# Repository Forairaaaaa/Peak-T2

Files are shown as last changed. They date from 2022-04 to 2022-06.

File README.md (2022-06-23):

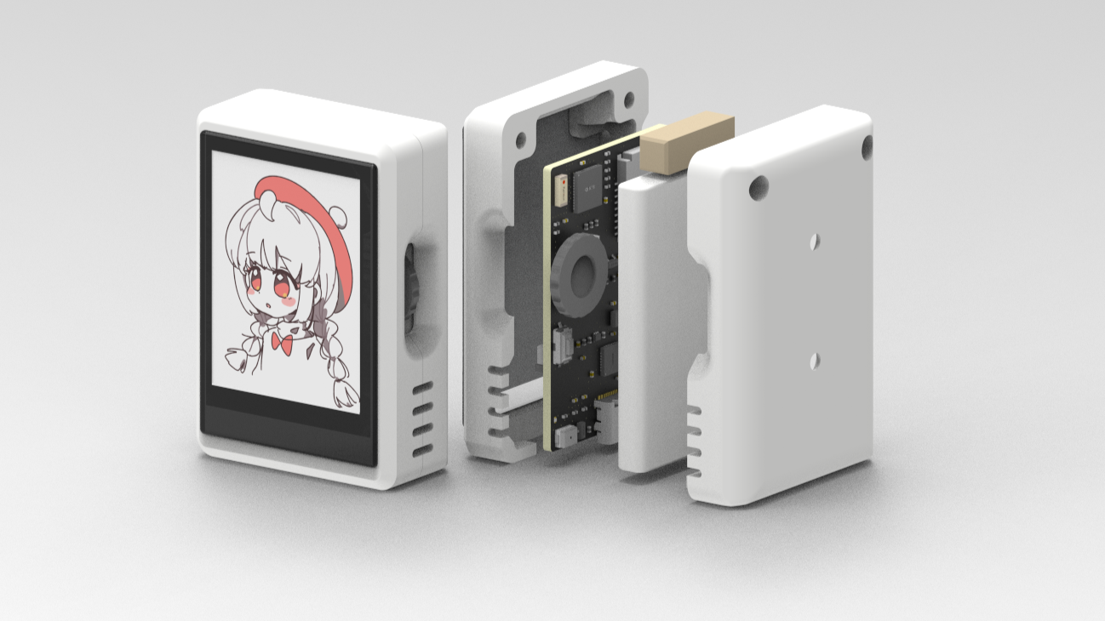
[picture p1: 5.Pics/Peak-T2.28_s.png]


# 基于ESP32的2.0英寸触摸屏小终端

#### 视频介绍~：

- https://www.bilibili.com/video/BV1934y1e74z?share_source=copy_web

#### 设计参考：

- https://github.com/peng-zhihui/Peak
- https://github.com/FASTSHIFT/X-TRACK

#### 硬件配置：

| 主控 | ESP32-PICO-D4 |
| --- | --- |
| 屏幕 | ST7789 IPS 2.0英寸LCD  SPI接口 分辨率：240x320 |
| 输入设备 | CST026 2.0英寸电容触摸屏  分辨率：240x320  、  旋转编码器 |
| 输出设备 | 一颗用户LED、蜂鸣器 |
| 储存 | TF卡槽  SPI接口 |
| IMU | MPU6050  I2C接口 |
| GPS | ATGM336H模块  UART接口 |
| 电池 | Li-ion 3.7V 603450 1200mAh |
| 电源管理 | ME6215C33M5G + MCP73831 |
| USB接口  | Type-C座，CP2102自动下载电路 |

详细参考链接：[1.Hardware · Forairaaaaa/Peak-T2 - 码云 - 开源中国 (gitee.com)](https://gitee.com/forairaaaaa/peak-t2/tree/master/1.Hardware)

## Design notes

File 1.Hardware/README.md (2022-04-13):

#### 立创开源平台链接：

#### https://oshwhub.com/eedadada/fed36bbc19da4527b237982f9cd09f99

PCB为4层板，电路及布局基本与稚晖君原版Peak无异。

#### 硬件配置：

| 主控 | ESP32-PICO-D4 |
| --- | --- |
| 屏幕 | ST7789 IPS 2.0英寸LCD  SPI接口 分辨率：240x320 |
| 输入设备 | CST026 2.0英寸电容触摸屏  分辨率：240x320  、  旋转编码器 |
| 输出设备 | 一颗用户LED、蜂鸣器 |
| 储存 | TF卡槽  SPI接口 |
| IMU | MPU6050  I2C接口 |
| GPS | ATGM336H模块  UART接口 |
| 电池 | Li-ion 3.7V 603450 1200mAh |
| 电源管理 | ME6215C33M5G + MCP73831 |
| USB接口  | Type-C座，CP2102自动下载电路 |

#### 焊接建议：

- 鉴于ESP32-PICO-D4封装问题，建议使用钢网配合加热平台或风枪
- 旋转编码器焊盘建议使用烙铁加固，只经过普通加热台焊接容易焊不稳（别问怎么知道的

#### 注意问题：

- **烧录程序时需要接上电池，不然烧录时会出现电压问题报错**
- **烧录程序时需要保持按下编码器，为芯片供电**
- 由于电池座旁边有几个元器件，拔电池插头时要小心方向，别把旁边的小器件也顺下来了（
- PCB底层上的芯片电源使能电阻使用了0603封装，确实不如0402方便（可以直接连锡）
- GPS模块不需要的可以不焊接，或者替换自己的小模块，要注意相关引脚问题，详细在原理图有说明
- 同理MPU6050、触摸屏也可以裁剪掉，这两者使用同一组I2C总线

#### 器件链接参考：

- 电池：[伯朗 导航行车记录仪锂电池大容量通用3.7v聚合物胎压蓝牙耳机5V-tmall.com天猫](https://detail.tmall.com/item.htm?id=579820162048&spm=a1z09.2.0.0.5eaf2e8dkwSGBJ&_u=b2bdtj0f1990) 分类：耐高温80度-603450-1200毫安
- 外壳固定铜柱：[M2*4/5/6/8/9/10/11/12 双通 监控铜柱 滚花安防铜柱（10只）-淘宝网 (taobao.com)](https://item.taobao.com/item.htm?spm=a1z09.2.0.0.5eaf2e8dkwSGBJ&id=555117890802&_u=b2bdtj0fff40) 分类：双通 M2*4
- GPS模块：[ATGM336H GPS 北斗双模模块 飞控 带EEPROM 替代NEO-M8N-淘宝网 (taobao.com)](https://item.taobao.com/item.htm?spm=a1z09.2.0.0.5eaf2e8dkwSGBJ&id=595353912203&_u=b2bdtj0f9a41)
- LCD屏幕：[2寸lcd显示屏2.0寸显示屏高清ips显示屏st7789驱动spi/并口240320-淘宝网 (taobao.com)](https://item.taobao.com/item.htm?spm=a1z09.2.0.0.5eaf2e8dkwSGBJ&id=653306169973&_u=b2bdtj0faa53)
- 电容触摸屏：[2寸CTP电容触摸屏2.0寸小尺寸触摸屏 FT6236U FT6336G CST026-淘宝网 (taobao.com)](https://item.taobao.com/item.htm?spm=a1z09.2.0.0.5eaf2e8dkwSGBJ&id=607113397517&_u=b2bdtj0f8e5c)
- CP2102可用CH9102X代替







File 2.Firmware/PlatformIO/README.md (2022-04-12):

### X-Trak_fw

这是一开始尝试移植X-Track的工程，HAL库没有很完善，开机动画后会出现空指针问题。

### Arduino_fw

这里是比较完善的HAL库和lvgl移植，可以使用这个固件跑lvgl demo测试硬件，里面还有一个我参考X-Track界面写的一个码表，可以测试GPS功能。

如果想使用稚晖君的Peak_fw，可以直接编译上传，理论上只需修改屏幕分辨率就行（不改也行），外设引脚是一样的。

##### 已实现功能：

- 主程序中有个lvgl demo函数被注释，需要测试lvgl功能的可以自行选择编译

  ###### 码表程序中：

- 当前速度、平均速度、最大速度、里程、运动时长的显示

- 北京时间、电池电量（不是很准）、GPS卫星数的显示

- 编码器的亮度调节，调节到极限时会触发提示音

##### 已知问题：

- 触摸屏驱动移植自M5Core2，没有修改完善，触摸时常会失灵，重启又好了
- Arduino_fw下的HAL::SD库有问题，不过在lib里加上稚晖君Peak所使用的SD和SPI库可以正常使用
- 码表里的地图和菜单按钮只是摆设，电池图标也还没有写刷新函数
- 星期四要完成毕业论文初稿，而我只写了一章却还在写这玩意（

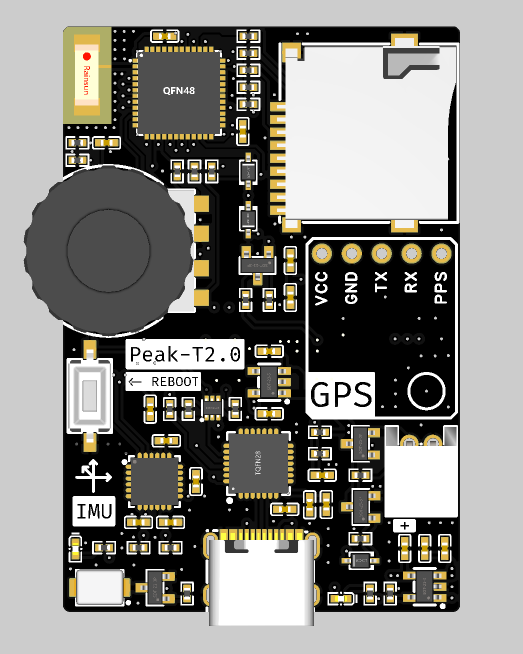
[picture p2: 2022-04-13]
5.Pics/pcb2.png

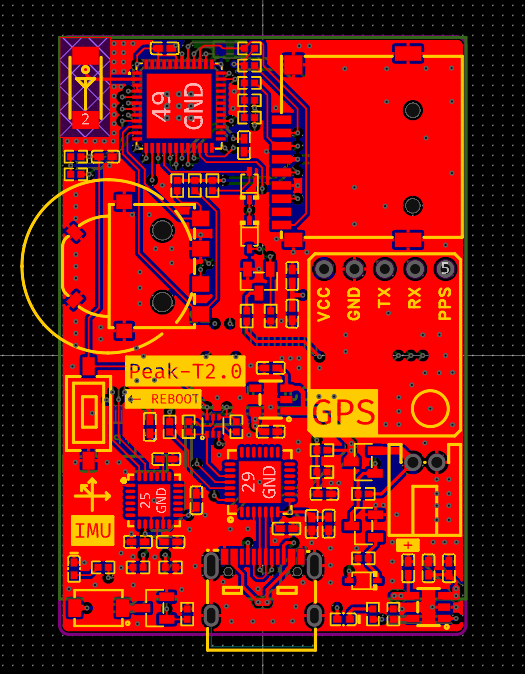
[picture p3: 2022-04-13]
5.Pics/pcb.png

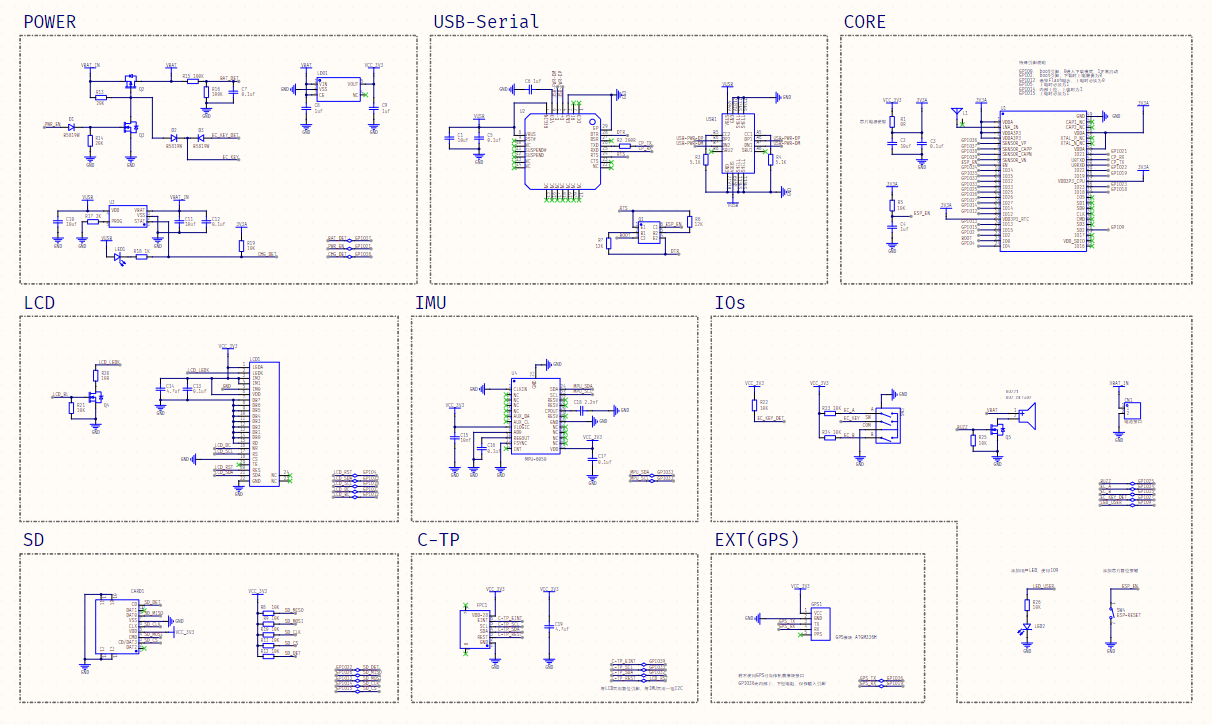
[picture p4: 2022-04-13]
5.Pics/sch.png

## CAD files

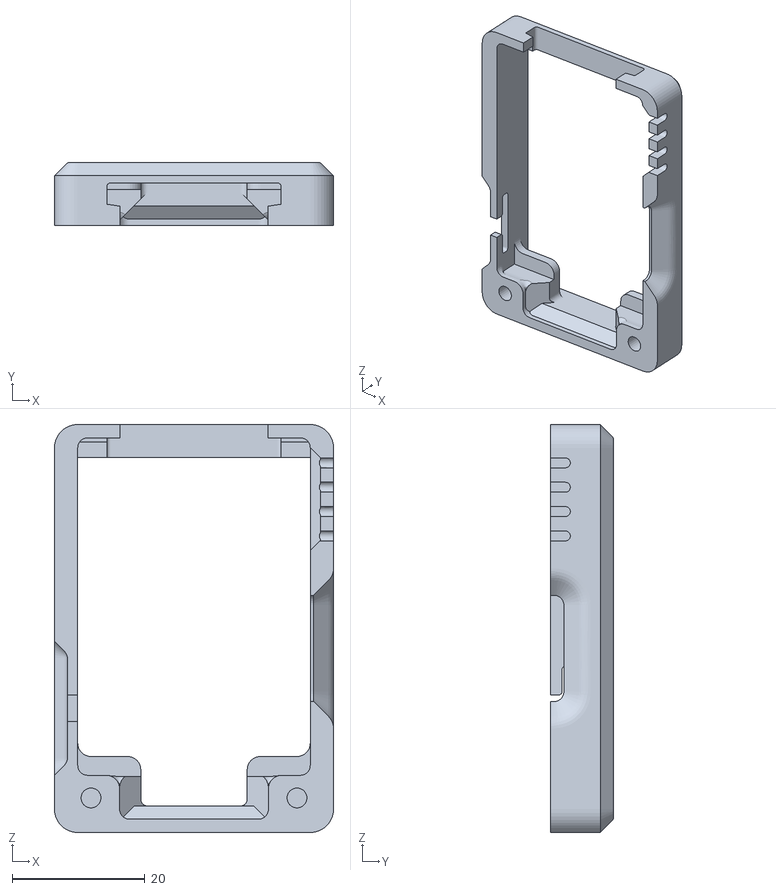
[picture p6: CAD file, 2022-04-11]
4.Model/STL/顶层.stl
42.0 x 9.50 x 61.4

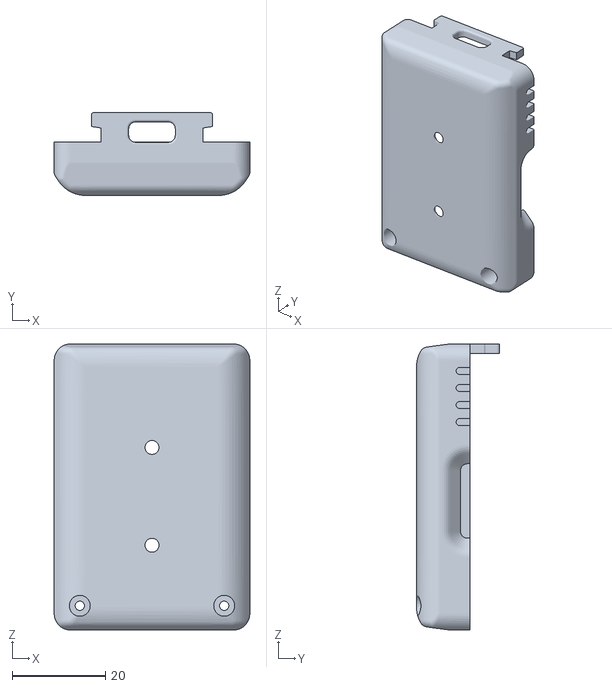
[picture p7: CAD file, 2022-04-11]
4.Model/STL/底层.stl
42.0 x 17.8 x 61.4

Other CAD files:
4.Model/Peak-T2.0_Shell.f3d

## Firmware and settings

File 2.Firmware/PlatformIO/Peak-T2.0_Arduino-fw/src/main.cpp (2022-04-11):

#include <Arduino.h>
#include "HAL/HAL.h"
#include "Port/Display.h"
#include "PeakTrack/PeakTrack.h"
#include "lv_demo.h"


#include "HAL/HAL_Def.h"


void lvgl_test(char i)
{
    switch (i) {
    case 0:
        lv_demo_benchmark();
        break;
    case 1:
        lv_demo_widgets();
        break;
    case 2:
        lv_demo_stress();
        break;
    case 3:
        lv_demo_keypad_encoder();
        break;
    case 4:
        lv_demo_music();
        break;
    default:
        break;
    } 
}



void setup()
{
    HAL::HAL_Init();
    Port_Init();

    /* lvgl test */
    // lvgl_test(100);
    Peak_Track_init();

    /* Enable lvgl task */
    INIT_DONE();
}

void loop()
{
    HAL::HAL_Update();
}

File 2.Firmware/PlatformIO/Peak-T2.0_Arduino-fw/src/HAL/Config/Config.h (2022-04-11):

/*
 * MIT License
 * Copyright (c) 2021 _VIFEXTech
 *
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
 * THE SOFTWARE IS PROVIDED "AS IS", WITHOUT WARRANTY OF ANY KIND, EXPRESS OR
 * IMPLIED, INCLUDING BUT NOT LIMITED TO THE WARRANTIES OF MERCHANTABILITY,
 * FITNESS FOR A PARTICULAR PURPOSE AND NONINFRINGEMENT. IN NO EVENT SHALL THE
 * AUTHORS OR COPYRIGHT HOLDERS BE LIABLE FOR ANY CLAIM, DAMAGES OR OTHER
 * LIABILITY, WHETHER IN AN ACTION OF CONTRACT, TORT OR OTHERWISE, ARISING FROM,
 * OUT OF OR IN CONNECTION WITH THE SOFTWARE OR THE USE OR OTHER DEALINGS IN THE
 * SOFTWARE.
 */
#ifndef __CONFIG_H
#define __CONFIG_H

/*=========================
   Application configuration
 *=========================*/




/*=========================
   Hardware Configuration
 *=========================*/

/* Screen */
// #define CONFIG_SCREEN_CS_PIN        PB0
// #define CONFIG_SCREEN_DC_PIN        PA4
// #define CONFIG_SCREEN_RST_PIN       PA6
// #define CONFIG_SCREEN_SCK_PIN       PA5
// #define CONFIG_SCREEN_MOSI_PIN      PA7
#define CONFIG_SCREEN_BLK_PIN       12
#define CONFIG_SCREEN_HOR_RES       240
#define CONFIG_SCREEN_VER_RES       320
#define CONFIG_SCREEN_BUFFER_SIZE   (CONFIG_SCREEN_HOR_RES * CONFIG_SCREEN_VER_RES / 10)

/* Touch screen */
#define CST_DEVICE_ADDR 0x38
#define CST_INT 39

/* Battery */
#define CONFIG_BAT_DET_PIN          37
#define CONFIG_BAT_CHG_DET_PIN      38

/* Buzzer */
#define CONFIG_BUZZ_PIN             25
#define CONFIG_BUZZ_CHANNEL         2
#define CONFIG_SOUND_ENABLE_DEFAULT true

/* GPS */
#define CONFIG_GPS_SERIAL           Serial1
#define CONFIG_GPS_USE_TRANSPARENT  0
#define CONFIG_GPS_BUF_OVERLOAD_CHK 0
#define CONFIG_GPS_TX_PIN           36
#define CONFIG_GPS_RX_PIN           19

/* IMU */
#define CONFIG_IMU_INT1_PIN         32
#define CONFIG_IMU_INT2_PIN         33

/* I2C */
#define CONFIG_MCU_SDA_PIN          32
#define CONFIG_MCU_SCL_PIN          33

/* Encoder */
#define CONFIG_ENCODER_B_PIN        34
#define CONFIG_ENCODER_A_PIN        35
#define CONFIG_ENCODER_PUSH_PIN     27
#define CONFIF_ENCODER_CHANGE_BACKLIGHT_ENABLE true
#define CONFIF_ENCODER_CHANGE_BACKLIGHT_WEIGHT 100

/* Power */
#define CONFIG_POWER_EN_PIN         21
#define CONFIG_POWER_WAIT_TIME      1000
#define CONFIG_POWER_SHUTDOWM_DELAY 5000

/* Debug USART */
#define CONFIG_DEBUG_SERIAL         Serial

/* SD CARD */
#define CONFIG_SD_SPI               SPI_SD
#define CONFIG_SD_CD_PIN            -1
#define CONFIG_SD_MOSI_PIN          PB15
#define CONFIG_SD_MISO_PIN          PB14
#define CONFIG_SD_SCK_PIN           PB13
#define CONFIG_SD_CS_PIN            15
#define CONFIG_SD_DET_PIN           22


#endif

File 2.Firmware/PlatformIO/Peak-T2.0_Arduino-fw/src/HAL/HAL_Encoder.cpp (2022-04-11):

#include "HAL.h"
#include "ButtonEvent.h"

static ButtonEvent EncoderPush(CONFIG_POWER_SHUTDOWM_DELAY);

static bool EncoderEnable = true;
static volatile int16_t EncoderDiff = 0;
static bool EncoderDiffDisable = false;

static uint32_t backLight = 0;

// static void Buzz_Handler(int dir)
// {
//     static const uint16_t freqStart = 2000;
//     static uint16_t freq = freqStart;
//     static uint32_t lastRotateTime;

//     if(millis() - lastRotateTime > 1000)
//     {
//         freq = freqStart;
//     }
//     else
//     {
//         if(dir > 0)
//         {
//             freq += 100;
//         }

//         if(dir < 0)
//         {
//             freq -= 100;
//         }

//         freq = constrain(freq, 100, 20 * 1000);
//     }

//     lastRotateTime = millis();
//     HAL::Buzz_Tone(freq, 5);
// }

static void Encoder_EventHandler()
{
    // if(!EncoderEnable || EncoderDiffDisable)
    // {
    //     return;
    // }

    // int dir = (digitalRead(CONFIG_ENCODER_B_PIN) == LOW ? -1 : +1);
    // EncoderDiff += dir;
    // Buzz_Handler(dir);


    if (!EncoderEnable || EncoderDiffDisable)
    {
        return;
    }

    static volatile int count, countLast;
    static volatile uint8_t a0, b0;
    static volatile uint8_t ab0;
    uint8_t a = digitalRead(CONFIG_ENCODER_A_PIN);
    uint8_t b = digitalRead(CONFIG_ENCODER_B_PIN);
    if (a != a0)
    {
        a0 = a;
        if (b != b0)
        {
            b0 = b;
            count += ((a == b) ? 1 : -1);
            if ((a == b) != ab0)
            {
                count += ((a == b) ? 1 : -1);
            }
            ab0 = (a == b);
        }
    }

    if (count != countLast)
    {
        EncoderDiff += (count - countLast) > 0 ? 1 : -1;
        countLast = count;
    }

}

static void Encoder_PushHandler(ButtonEvent* btn, int event)
{
    if(event == ButtonEvent::EVENT_PRESSED)
    {
        HAL::Buzz_Tone(500, 20);
        EncoderDiffDisable = true;
    }
    else if(event == ButtonEvent::EVENT_RELEASED)
    {
        HAL::Buzz_Tone(700, 20);
        EncoderDiffDisable = false;
    }
    else if(event == ButtonEvent::EVENT_LONG_PRESSED)
    {
        HAL::Audio_PlayMusic("Shutdown");
        HAL::Power_Shutdown();
    }
}

void HAL::Encoder_Init()
{
    // pinMode(CONFIG_ENCODER_A_PIN, INPUT_PULLUP);
    // pinMode(CONFIG_ENCODER_B_PIN, INPUT_PULLUP);
    // pinMode(CONFIG_ENCODER_PUSH_PIN, INPUT_PULLUP);

    // attachInterrupt(CONFIG_ENCODER_A_PIN, Encoder_EventHandler, FALLING);

    // EncoderPush.EventAttach(Encoder_PushHandler);

    pinMode(CONFIG_ENCODER_A_PIN, INPUT_PULLUP);
    pinMode(CONFIG_ENCODER_B_PIN, INPUT_PULLUP);
    pinMode(CONFIG_ENCODER_PUSH_PIN, INPUT_PULLUP);
    attachInterrupt(CONFIG_ENCODER_A_PIN, Encoder_EventHandler, CHANGE);
    EncoderPush.EventAttach(Encoder_PushHandler);

}

void HAL::Encoder_Update()
{
    EncoderPush.EventMonitor(Encoder_GetIsPush());
}

void changeBacklight(int16_t diff)
{
    backLight = HAL::Backlight_GetValue() - (diff * CONFIF_ENCODER_CHANGE_BACKLIGHT_WEIGHT);

    if (backLight > 1024)
        HAL::Buzz_Tone(900, 40);
    
    // HAL::Backlight_SetValue(backLight);
    HAL::Backlight_SetGradual(backLight, 100);
}

int32_t HAL::Encoder_GetDiff()
{
    // int32_t diff = EncoderDiff;
    // EncoderDiff = 0;
    // return diff;

    int16_t diff = -EncoderDiff / 2;
    if (diff != 0)
    {
        // EncoderDiff是实际的脉冲数；把本次变量用掉了，需要重新置0
        EncoderDiff = 0;
        // Encoder_RotateHandler(diff);
        HAL::Buzz_Tone(300, 5);

        #if CONFIF_ENCODER_CHANGE_BACKLIGHT_ENABLE == true
            changeBacklight(diff);
        #endif
    }

    return diff;
}

bool HAL::Encoder_GetIsPush()
{
    if(!EncoderEnable)
    {
        return false;
    }
    
    return (digitalRead(CONFIG_ENCODER_PUSH_PIN) == LOW);
}

void HAL::Encoder_SetEnable(bool en)
{
    EncoderEnable = en;
}
